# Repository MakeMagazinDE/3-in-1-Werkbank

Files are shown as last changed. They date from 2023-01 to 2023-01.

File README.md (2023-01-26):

GitHub Logo

Maker Media GmbH

***

# 3-in-1-Werkbank

## Kompatibel zum 20mm-Festool-Lochraster

**Diese mobile Maker-Werkbank ist ein Multitalent: Befestigt man sie mit Schraubzwingen am Küchentisch, sorgt sie für eine angenehme Arbeitshöhe und bietet verschiedene Spannmöglichkeiten. Hängt man sie an die Wand, wird sie zum Werkzeugregal. Und dreht man sie um, verwandelt sie sich in eine Werkzeugkiste. Außerdem ist sie schnell und günstig gebaut.**

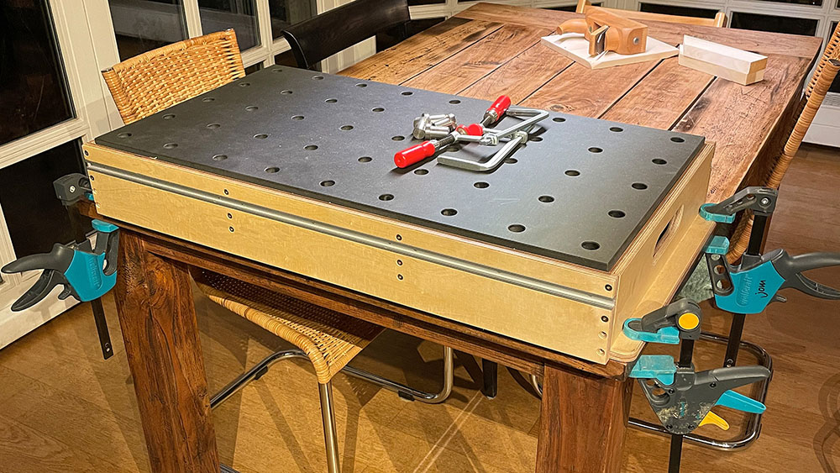
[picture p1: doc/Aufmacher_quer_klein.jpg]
Aufmacherbild aus dem Heft


Hier gibt es die Materialliste, die Zuschnittliste, eine Explosionszeichnung sowie ein 3D-Modell aus SketchUp.

Der vollständige Artikel zum Projekt steht in der **[Make-Ausgabe 1/23 ab Seite 102](https://www.heise.de/select/make/2023/1/2220213363003207970)**.

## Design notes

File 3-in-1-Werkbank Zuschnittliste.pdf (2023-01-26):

Übersicht

Typ | Material / Dicke | Anzahl | Σ Rohmaße
Länge | Fläche | Volumen
- | MDF Schwarz / 19 mm | 1 | - | 0,375 m² | 0,007 m³
- | Multiplex / 15 mm | 10 | - | 0,446 m² | 0,007 m³
- | Aluminium | 2 | - | - | -
MDF Schwarz / 19 mm | Faser in Längsrichtung
Nr. | Bezeichnung | Anz. | Fertigmaß
L | B
A | Tischplatte | 1 | 834 mm | 450 mm
Multiplex / 15 mm | Faser in Längsrichtung
Nr. | Bezeichnung | Anz. | Fertigmaß
L | B
B | Seite lang | 2 | 864 mm | 120 mm
C | Seite kurz | 2 | 450 mm | 105 mm
D | Strebe | 2 | 450 mm | 100 mm
E | Fuß | 2 | 450 mm | 45 mm
F | Auflage | 2 | 450 mm | 15 mm

Aluminium

Nr. | Bezeichnung | Anz.
G | C-Schiene Länge: 864mm | 1
H | C-Schiene Länge: 864mm | 1

## Holzliste

### 3-in-1-Werkbank.skp

2023-01-26 14:33 Millimeter

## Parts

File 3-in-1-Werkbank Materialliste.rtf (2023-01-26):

- Holzschrauben 28 Stück 6x50
- Gewindeschrauben 4 Stück M8x60 (Befestigung der Tischplatte)
- Zylindermuttern 4 Stück M8x15 (Befestigung der Tischplatte)
- Unterlegscheiben 4 Stück M8 (Befestigung der Tischplatte)
- C-Nut-Profile 2 Stück 1000mm, auf 864mm kürzen
- Gewindeschrauben 10 Stück M3x16 (Befestigung C-Nut-Profil)
- Unterlegscheiben 10 Stück M3 (Befestigung C-Nut-Profil)
- Muttern 10 Stück M3 (Befestigung C-Nut-Profil)

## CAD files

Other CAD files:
3-in-1-Werkbank.skp

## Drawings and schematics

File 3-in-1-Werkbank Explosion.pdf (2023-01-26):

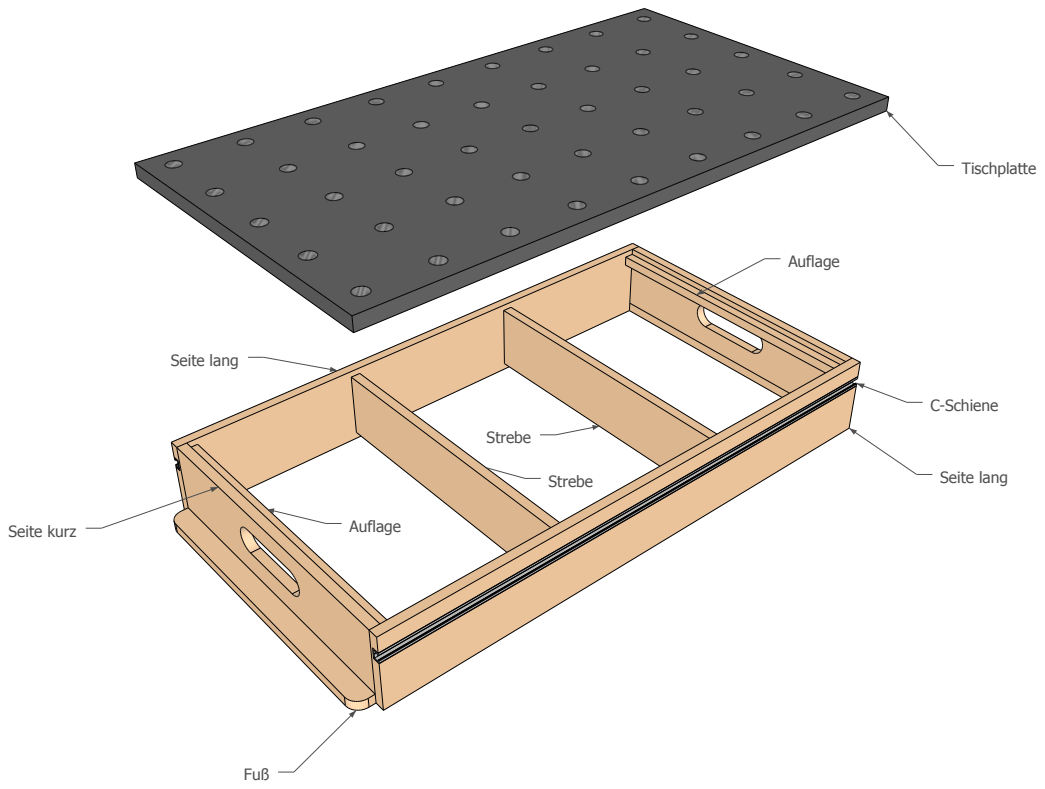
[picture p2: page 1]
Tischplatte; Seite lang; Fuß; Seite kurz; Auflage; Strebe; C-Schiene
